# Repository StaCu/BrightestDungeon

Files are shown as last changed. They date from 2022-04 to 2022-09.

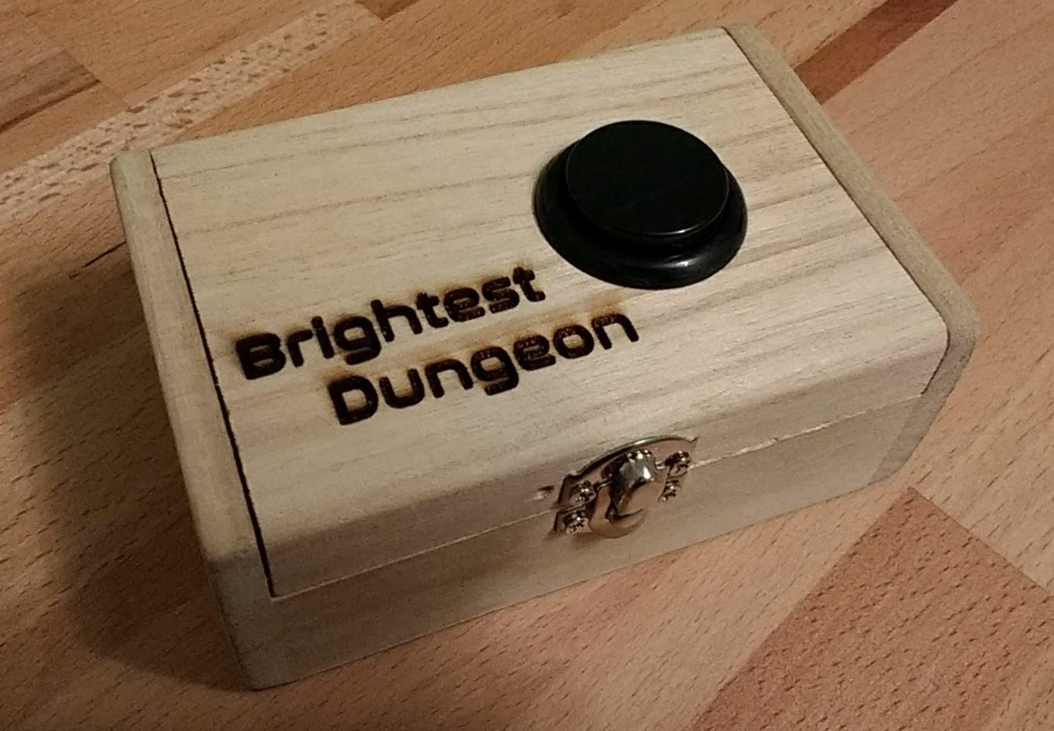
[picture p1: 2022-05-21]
cad/img/2022-04-29 Laser Engraving.jpeg

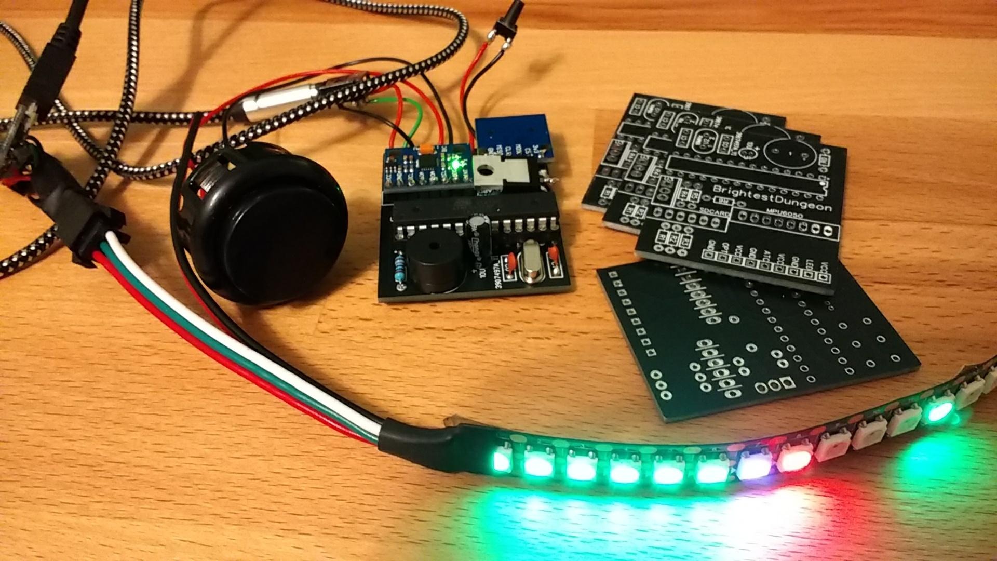
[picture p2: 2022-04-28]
cad/img/2022-03-05 PCB.jpeg

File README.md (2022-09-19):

# Brightest Dungeon

A 1D dungeon arcade&puzzle game inspired by a game I saw at 35C3.

BrightestDungeon is rather simple: You are the green dot and can move on a one dimensional led strip, but beware the red dots!
Fend for yourself against the evil monsters and progress through the different levels of the dungeon.
But keep in mind that BrightestDungeon is, at heart, a puzzle game.
Finishing a floor is not as simple as killing all the enemies within it.
You will have to prove your wits and worthiness by solving the puzzle on each floor.

## Getting it up and running

The minimal hardware requirements to play BrightestDungeon include a microcontroller (Atmega328p), LED strip (WS2812), potentiometer and a button.
An accelerometer (MPU6050), sound driver and sdcard reader can improve the experience.
The code can be easily ported to other platforms as well.
Alternatively, one can also be play from the linux terminal.

### Microcontroller

Each supported platform has a file platform/\<platform\>/Platform.md , which contains information about which components are
required, how to wire them as well as information about how to en-/disable some of them.

To program the microcontroller with Arduino IDE, open BrighestDungeon.ino and copy the required libraries.
To upload the code with PlatformIO, use one of the following lines:

```
pio run -e <environment> --target upload
pio run -e <environment> --target upload && pio device monitor
```

### Simulator

To run the simulator and play the game inside the terminal, run:

```
pio run -e simulator && .pio/build/simulator/program
```

The ncurses library is a prerequisite.
It is preinstalled on most linux distibutions, or can be installed using:

```
sudo apt install libncurses-dev
```

You can play using A (left), D (right), S (attack), E (options), Q (quit).
However, this meant to be more for debugging and creating new levels rather than actually playing BrightestDungeon.

## Project Structure

The following is a simplified structure of the project to show where to find information about its different parts.

folder/file                  | content
-----------------------------|-------------
cad/                         |
\|-- img/                    | some images to look at
\|-- Build Instructions.md   | how to build the game
dng/                         |
\|-- 0-f/                    | sdcard-loadable dungeons
\|-- Create Dungeon.md       | how to create new dungeons/floors/rooms
\|-- Entity Cheat Sheat.md   | explanation of each entity
\|-- Runtime Settings.md     | explanation of runtime settings
\|-- template.txt            | template for a dungeon room
platform/                    |
\|-- lib/                    | common libraries
\|-- \<platforms\>/          | 
\|-- \|-- lib/               | libraries for each platform
\|-- \|-- Platform.md        | information about the platform
\|-- Porting.md              | how to port to a new platform
src/                         | 
BrightestDungeon.ino         | entry point for ArduinoIDE
LICENSE                      | GPLv3
platformio.ini               | build tool instructions
README.md                    | this file
sdcard.sh                    | copy everything to an sdcard

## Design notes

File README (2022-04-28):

# Brightest Dungeon

A 1D dungeon arcade&puzzle game inspired by a game I saw at 35C3.

Brightest Dungeon is rather simple: You are the green dot and can move on a one dimensional led strip, but beware the red dots!
Fend for yourself and progress through the different levels of the dungeon.
But keep in mind that Brightest Dungeon is, at heart, a puzzle game.
Finishing a floor is not as simple as killing all the enemies within it.
You will have to prove your wits and worthiness by solving the puzzle each floor represents.

## Entity Cheat Sheet

List of all the entities, puzzle pieces and stuff to watch out for in the dungeon.

Entity             | Visual              | Description
-------------------|---------------------|-------------------------
Lives              | green/blue/red dots | the first few leds show how many lives you have left (not so important when using checkpoints)
Hero               | green/blue dot      | you
 - Goal            | green/blue          | your goal (not every room has one, always at the end)
 - Sword           | cyan line           | your default attack
 - Shot            | cyan dot            | your special attack (lost on death)
Item               |                     |     
 - sword/shot      |                     | swap attack type
 - set color green |                     | change your color to green
 - set color blue  |                     | change your color to blue
 - invert control  |                     | invert control
 - extra life      |                     | +1 live (capped at MAX_LIVES)
-------------------|---------------------|-------------------------
Monster            | red dot             | move back and forth, (do not touch!)
 - Spawner         | none                | spawns new monsters
Worm               | moving red line     | a bit smarter than normal monsters
Boss               | red line            | has multiple lives and spawns monsters
-------------------|---------------------|-------------------------
Button             | white/gray line     | [^0] with a timed behaviour
Door               | white line          | enter another room on the same floor
Fog                | pink line           | hides anything underneath it
ForceField         | blue/green flicker  | you can only pass through if you have matching colors
Lava               | orange flicker      | save to cross when it does not flicker
Mine               | yellow dot          | explodes (do not touch!)
Portal             | orange/blue line    | the cake is a lie!
Switch             | white/gray line     | [^0] with a back and forth behaviour
Wall               | white line          | blockade
Water              | moving blue dots    | the current drags you along with it

[^0] Brightest Dungeon employs a masking system to change parts of the active room.
Loading a room loads EVERY entity within it.
However, each entity has a mask that determines whether it is visible, updated and part of collisions.
Moving over a button or pressing a switch changes which entities are masked (though some are always there).

## Getting it up and running

Here is a list of the different hardware elements required to run the game.

### Atmega328P (16MHz)

The game was originally developed for the Atmega328P, using it will not require any changes to the code base and all features
can be used. The Atmega328P must be clocked at 16MHz, because the LEDs used (WS2811) use a protocol depending on the correct
timing. The code to transmit the LED data was written so it works for 16MHz.

### Atmega168P (16MHz)

The game works on the smaller version of the Atmega328P, the Atmega168P, as well. However, some settings must be
disabled/reduced, because the Atmega168P doesn't have enough sram and progmem required for those features.
In src/Settings.h set ...
//#define USE_MPU6050_CONTROLLER
#define LED_STRIP_COUNT 300
#define LED_STATUS_COUNT 0
#define POOL_SIZE 40
#define ENABLE_SOUND false
#define SHORTEN_INTERNAL_DUNGEON true
#define ENABLE_FILE_LOADER false
#define USE_EEPROM false
#define ENABLE_LOGGING false
... and the program code should turn out to fit onto the Atmega168P together with a small bootloader.

### WS2812B

To save SRAM (and PROGMEM), the LED control code has been written in Assembler and is only compatible with WS2811 LEDs (and WS2812).
While the code is capable of addressing up to 2^16 LEDs, the MCU reaches its limit at around 500 of them, beyond of which
it is not capable of delivering 50 refreshes per second. Increasing UPDATE_TIME in src/Settings.h will allow for more
LEDs.
By default, the minimum number of LEDs is 100, as the level layout suffers from too few pixels.
Both, LED_MIN_COUNT and LED_STRIP_COUNT can be changed in src/Settings.h .
Some LED strips are terrible with regards to color correctness. 
#define COLOR_PALETTE 1
switches to a second color palette that ensures the different entities are still distinguishable (but the game will look worse).

### Simple Controller

The simple controller consists of a button for attacking and a potentiometer for moving.

### MPU6050

The better controller consists of a button for attacking and the MPU6050 for moving.

### Passive Buzzer

Used to generate the sound.

### SDCard Adapter and SDCard

To allow for new dungeons without the need to recompile, BrightestDungeon is capable of loading levels from an SDCard.

### Button

One button for entering the in game options menu.

### Pins

Most of the pins have been hardcoded (but the assembler code can of course be changed).
The default values are:
Usage             | Pin
------------------|---------------
Simple Controller |
 - Potentiometer  | A5
 - Attack Button  | D2
MPU6050           |
 - SCL            | A5
 - SDA            | A4
 - Attack Button  | D2
LED               |
 - Data           | D8
Sound             |
 - Passive Buzzer | D9, D10
Random            | A1 (to make random numbers more random)
Options           | D3
SD Card           | (many sdcard modules use 3.3V)
 - MOSI           | D11
 - MISO           | D12
 - CLK            | D13
 - CS             | D4

Connecting Ground and Vcc is all that is left.

## Setup

The compile time settings are all listed and explained within src/Settings.h .

### Microcontroller

To program the microcontroller with Arduino IDE, open BrighestDungeon.ino with it.
To upload the code with PlatformIO, use one of the following lines:

```
pio run --target upload
pio run --target upload && pio device monitor
```

### Simulator

The simulator can be started with a directory from which to load external dungeons and store the eeprom simulation and logging information.
To run the simulator and play the game inside the terminal, run:

```
mkdir build
cd build/
cmake .. 
make dungeon
./dungeon ../
```

The ncurses library is a prerequisite (preinstalled on most linux distibutions).
You can play using A (left), D (right), S (attack), E (options), Q (quit).
However, this meant to be more for debugging and creating new levels rather than actually playing BrightestDungeon.

### Secret Code

To generate a secret morse code that can be integrated into the game write the text to secret/main.cpp and run:

```
mkdir build
cd build/
cmake .. 
make secret
./secret
mv Secret.h ../src/Secret.h
```

###

To copy everything to an sdcard, run:

```
./sdcard.sh <path>
```

## Creating new Dungeons, Floors and Rooms

See /dng/README on how to write and load your own dungeons.

## In Game Settings

The runtime settings are listed within src/level/Options.cpp.
While they can be changed at runtime, their default values can be set in src/Settings.h.
When using the EEPROM feature to remember the settings, however, those default values become less important.

The options menu can be opened by pressing the OPTIONS_PIN.
This will show a level with multiple white, gray and green dashes.
Placing the hero on one of them and attacking will change the settings (the green dashes are only spacers and do nothing).

Options layout (WW: white, WG: white/gray, GG: green):
x    | description
-----|---------------------------------
WW   | callibrate the controller
WG   | invert the controller direction
GG   | ---
WW   | led_count --
WW   | led_count ++
WW   | brightness --
WW   | brightness ++
WW   | volume --
WW   | volume ++
GG   | ---
WG   | enable/disable checkpoints
GG   | ---
WG   | dungeon0 [^1]
WG   | dungeon1 [^1]
WG   | dungeon2 [^1]
WG   | dungeon3 [^1]
GG   | ---
WG   | floor0 [^2]
WG   | floor1 [^2]
WG   | floor2 [^2]
WG   | floor3 [^2]
WG   | floor4 [^2]
WG   | floor5 [^2]
WG   | floor6 [^2]
WG   | floor7 [^2]
GG   | ---
WW   | reload options from eeprom
WW   | write changes to eeprom
GG   | ---
Goal | exit options (keep changes until the next restart)

[^1] select one of 16 dungeons (0: internal, 1-15: sdcard);
     when opening the options, this will show the currently selected dungeon
[^2] select a floor from this dungeon and start from there (skip the previous floors);
     when checkpoints are disabled, this floor serves as a start point after loosing all lives;
     when opening the options, this will show the currently selected floor

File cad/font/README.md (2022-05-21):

# Font

I used Nasalization (https://typodermicfonts.com/).

Laser Engraving:
54mm * 20mm

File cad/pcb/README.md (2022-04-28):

# Parts

U1:         10uF Capacitor
C0,C1:      22pF Ceramic Capacitor
U2:         16MHz Quarz Crystal
R0:         10k Ohm Resistor
R1,R2,R3:   2k Ohm Resistor
R4,R5,R6:   1k Ohm Resistor
U3:         LM1117T 3.3V Voltage Regulator

Atmega328p
SDCard Reader

MPU6050 or Potentiometer
Button (ATC + GND)
Button (OPT + GND)
WS2811 (LED)

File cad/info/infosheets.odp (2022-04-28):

## Brightest Dungeon

A 1D Dungeon aRcade & Puzzle Game

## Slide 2

Brightest Dungeon is rather simple: You are the green dot and can move on a one dimensional led strip, but beware the red dots! Fend for yourself and progress through the different levels of the dungeon.

But keep in mind that Brightest Dungeon is, at heart, a puzzle game. Finishing a floor is not as simple as killing all the enemies within it. You will have to prove your wits and worthiness by solving the puzzle each floor represents.

## Hero

You

Your goal

Move by tilting the Gamebox

## Monster

Moves back and forth (do not touch!)

## Attack

Attack by pressing the button

Sword: your default attack

Shot: your special attack (lost on death)

## Lives

Lives

+1 live

Loosing all lives

resets the current

floor

2 dots orbiting another dot

## Colors

Forcefield

(flickers green/blue)

You can only pass through if you have matching colors

Colorchange

(green/blue)

Change your color to green/blue

## Worm

A bit smarter than normal monsters

## Boss

Has multiple lives and spawns monsters

If a boss is present, you can only progress

to the next floor after defeating it

## Button

Move over to make changes to the floor

(may revert after some time)

Colors darken on activation

## Door

Enter another room on the same floor

## Fog

Hides anything underneath it

## Lava

Save to cross when it does not flicker

Flickers

## Mine

Explodes (do not touch!)

## Portal

The cake is a lie!

Go in here...

...come out here!

## Switch

Press to make changes to the floor

(press again to revert)

Colors invert on activation

## Wall

Blockade, can’t pass through

## Water

The current drags you along with it

Pattern moves

## OPTIONS 1

Calibrate

Invert Controls

++++++

#LED --

#LED ++

Brightness --

Brightness ++

Volume --

Volume ++

++++++

Leaving the Level keeps the changes until the next restart

Writing to EEPROM saves the changes permanently

## OPTIONS 2

Enable/Disable Checkpoints

++++++

Select Dungeon [0-15] (0: Internal, 1-15: SDCard)

++++++

Select Start Floor [0-255]

++++++

Read Options from EEPROM

Write Options to EEPROM

++++++

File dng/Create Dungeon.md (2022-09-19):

# Creating new Dungeons, Floors and Rooms

First up, in Platform.h ENABLE_FILE_LOADER must be defined as true.

## Background

Brightest Dungeon loads a room by using the following path scheme:
/dng/X/YYY/ZZZ.txt
X: dungeon number [0-f]
YYY: floor number [0-255]
ZZZ: room number [0-255]

If the file does not exist, it will be treated like the player having beaten the entire dungeon (i.e. showing the victory animation).
If the file does exist, loading it will be successful, no matter the content.
Anything that does not match the correct syntax will be ignored or interpreted as 0.

## Creating a dungeon

A dungeon simply consists of multiple floors, starting with floor 000.
After finishing a floor, the next one is loaded.
If no room 000 exists within the next floor, the player has finished the dungeon.

## Creating a floor

A floor consists of one or more rooms, with one room being the 000 (the first room of the floor).
Doors can be used to switch between the different rooms.
Due to limited memory, (re-)loading a room will restore every entity that got destroyed previously (this actually makes for an interesting puzzle mechanic).

## Creating a room

A room is 250 units long and updated 50 times per second (every UPDATE_TIME ms).
Each unit consists of 32 sub steps.
 => speed of 10 results in 10 * 50 / 32 = 15.625 steps/second
I find that a speed of 3 to 20 is reasonable for monsters and water current.

The text file describing a room is read line by line.

### Entities

Each line contains one entity and its parameters.

 name       | parameters               | length | hint
------------|--------------------------|--------|-----
 NEXT       |                          |        | there is a goal at the end to progress to the next floor [^0]
 END        |                          |        | there is no goal at the end to progress to the next floor (optional) [^0]
 RESET      | mask                     |        | resets the specified bits of the global mask
------------|--------------------------|--------|-----
 HERO       | mask pos                 |    1   | must be a part of the level (otherwise it's a boring level...)
 \|         |                          |        | ofter death the previous spawn position is used (usually that is what you want)
 ITEM       | mask pos type            |    1   |
------------|--------------------------|--------|-----
 MONSTER    | mask pos speed           |    1   |
 BOSS       | mask pos pos pos         |   16   | a boss respawns 2 times
 WORM       | mask pos speed           |   16   |
 SPAWNER    | mask time time pos speed |    0   | the 1st time is the first activation,
 \|         |                          |        | the 2nd the interval for every
 \|         |                          |        | recurring activation
------------|--------------------------|--------|-----
 BUTTON     | mask pos op time time    |    6   |
 DOOR       | mask pos room pos        |    6   | the 2nd position is the destination
 FOG        | mask pos size speed      | size   |
 FORCEFIELD | mask pos color           |    6   |
 LAVA       | mask pos size time time  | size   | the 1st time is the first activation,
 \|         |                          |        | the 2nd the interval for every
 \|         |                          |        | recurring activation
 MINE       | mask pos                 |    1   |
 PORTAL     | mask pos pos             |    6   | the second position is the second portal
 SWITCH     | mask pos op              |    6   |
 WALL       | mask pos size            | size   |
 WATER      | mask pos size speed      | size   |
------------|--------------------------|--------|-----

[^0] anything after this will be ignored

### Parameters

 name  | range        | description
-------|--------------|-------------
 pos   | [0, 250]     |
 size  | [0, 250]     |
 speed | [-128, 127]  | note: the max player speed is slightly below 100
 time  | [0, 255]     | multiply by 100ms, 0 means no repetition
 room  | [0, 255]     | 
 type  | [1, 7]       | 0: set color to green (0), (default)
 \|    |              | 1: set color to blue (1),
 \|    |              | 2: swap sword <=> shot, (default: sword)
 \|    |              | 3: invert control direction, (default: not inverted)
 \|    |              | 4: extra life,
 color | [0, 1]       | 0: color green (0)
 \|    |              | 1: color blue (1)
 op    | [0, 255]     |
 mask  | [0, 255]     |
-------|--------------|-------------

Note: use binary notation by prefixing the number with a b or 0b (128 or 0b10000000).

### MASKING

Masks are a big part of the puzzle game. 
Each entity has a mask and there is a global mask.
The mask is used to decide, whether an entity is active.
Only then is it drawn, updated, and considered for collisions.
```
active = (entity_mask & global_mask) == entity_mask;
```

Switches and Buttons can change the global mask with the op parameter.
```
new_global_mask = global_mask ^ op;
```

When loading a new floor, the global mask is reset to 0b11110000 (this also means that it persists accross rooms and deaths on the same floor).
An entity with mask 0b10000000 will be active until the msb is flipped.
An entity with mask 0b00000001 will be inactive until the lsb is flipped.
An entity with mask 0b00000000 will always be active.

### COMMENTS

There are no comments.
If the first word does not match any of the keywords listed above, the line will be ignored.
Anything behind a complete command is also ignored.
A line has a maximum of FILEIO_BUFFER_SIZE (64) characters, anything beyond that is ignored.
If a number is missing or contains other symbols, it is interpreted as a 0.
 => there are no errors apart from "file not found".

```
BLABLA      this line will be treated as a "comment", because BLABLA is not a keyword
HERO as     this line will do the same as HERO 0 0, as does the next one
HERO                                                               1 2  (more than 64 chars)
HERO(0,0)   '(' ',' and '\t' are treated the same as ' '
```

The maximum amount of entities in the same room is POOL_SIZE, two of which are reserved for attacks.
Loading more entities will not do anything.
Keep in mind that a PORTAL comprises two entities.

### EXAMPLE

```
++ MAX LINE LENGTH +++++++++++++++++++++++++++++++++++++++++++++
HERO(0, 0)                # spawns a hero at position 0
LAVA(0, 50, 25, 0, 20)    # creates a lava pool at position 50
                          # with length 25. it activates after
                          # 0 seconds and switches between
                          # active/inactive every 20*100ms = 2sec
MONSTER(0, 200, 0)        # this monster will always show up
MONSTER(1, 210, 10)       # this monster is masked
NEXT                      # end of level
                          # once the hero reaches the goal, the
                          # next floor will be loaded
++ MAX LINE LENGTH +++++++++++++++++++++++++++++++++++++++++++++
```

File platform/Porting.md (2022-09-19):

# Porting Brightest Dungeon

- Put required libraries in platform/\<platform\>/lib
- Put platform specific code in platform/\<platform\>/lib/Platform/src
- Put information about the platform in platform/\<platform\>/Platform.md (minimum: pin usage and required libraries)
- Add new environment to platformio.ini

## Platform Specific Code

The platform specific code must implement all functions from platform/Platform.h
The files library.json and library.properties are also required for the build tool to find the code.
Folder structure:

folder/file                              | content
-----------------------------------------|-------------
platform/                                |
\|-- lib/                                | common libraries
\|-- \<platform\>/                       |
\|-- \|-- lib/                           | platform specific libraries
\|-- \|-- \|-- lib1/                     | required libraries
\|-- \|-- \|-- Platform/                 | 
\|-- \|-- \|-- \|-- src/                 | platform specific code
\|-- \|-- \|-- \|-- \|-- Platform.h      |
\|-- \|-- \|-- \|-- \|-- Platform.cpp    |
\|-- \|-- \|-- \|-- \|-- file1           |
\|-- \|-- \|-- \|-- library.json         | required by PlatformIO
\|-- \|-- \|-- \|-- library.properties   | required by ArduinoIDE
\|-- \|-- pcb/                           | PCB files
\|-- \|-- Platform.md                    | information about the platform
\|-- Platform.h                          | template for platform specific code
\|-- Porting.md                          | how to port to a new platform
platformio.ini                           | build tool instructions

See platform/simulator/ or platform/atmega328p for a simple example.

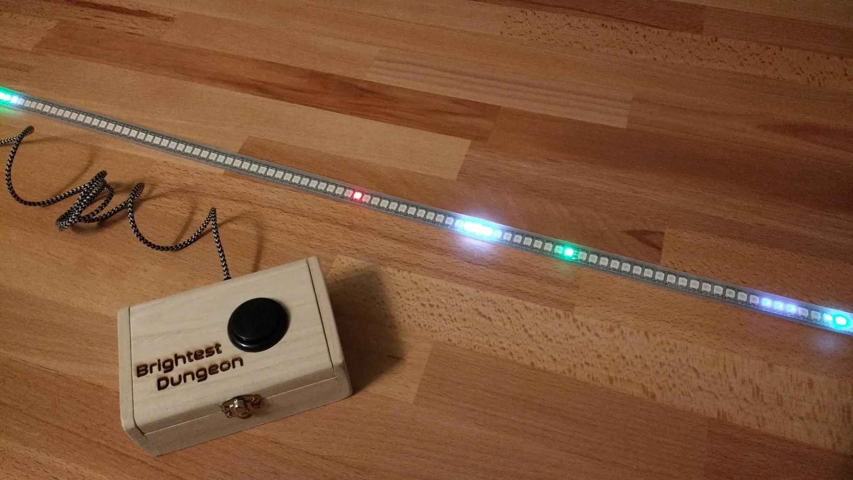
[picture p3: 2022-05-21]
cad/img/2022-05-21 2nd.jpeg

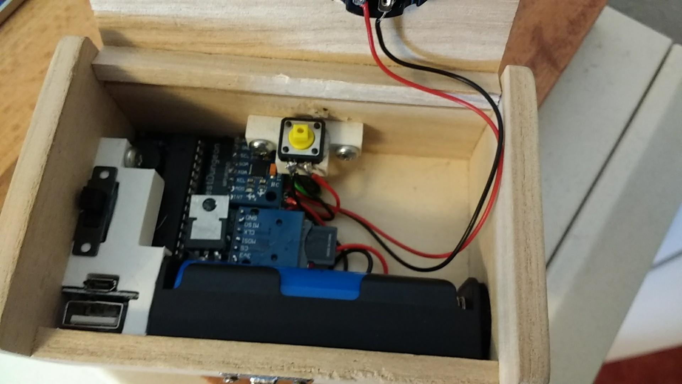
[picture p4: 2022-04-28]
cad/img/2022-04-16 Battery.jpeg

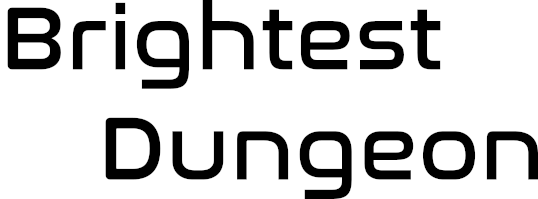
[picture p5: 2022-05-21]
cad/font/Text.png

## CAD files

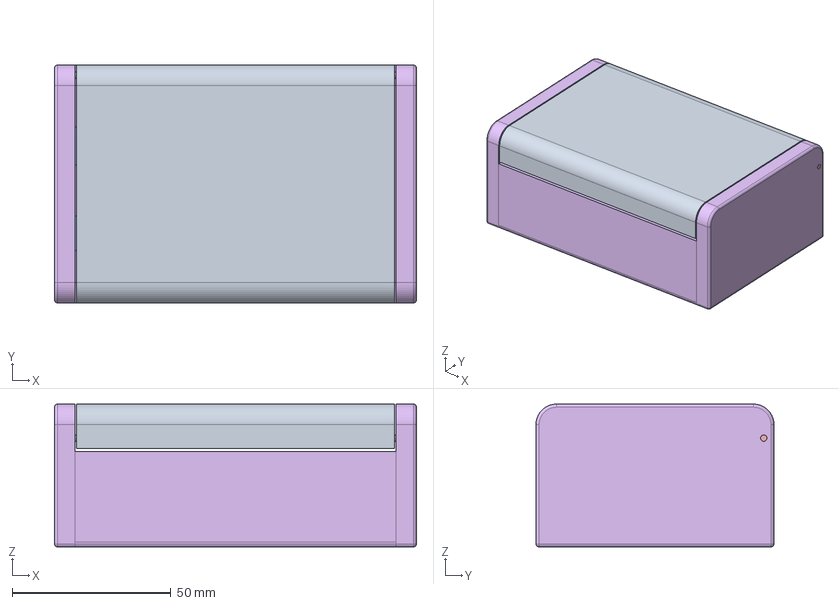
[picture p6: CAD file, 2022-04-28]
cad/box/Box.FCStd
114.0 x 75.0 x 45.0 mm
Top
ConnectorHolder
BMSHolder
BoxPinLeft
BoxPinRight

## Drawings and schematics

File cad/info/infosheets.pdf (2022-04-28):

# Brightest Dungeon

### A 1D Dungeon aRcade & Puzzle Game

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

# Hero

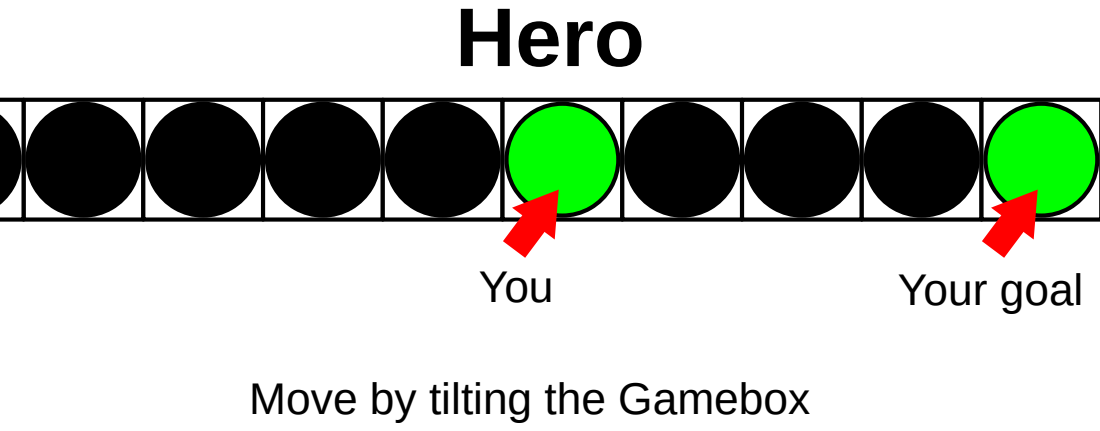
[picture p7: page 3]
You; Your goal

Move by tilting the Gamebox

# Monster

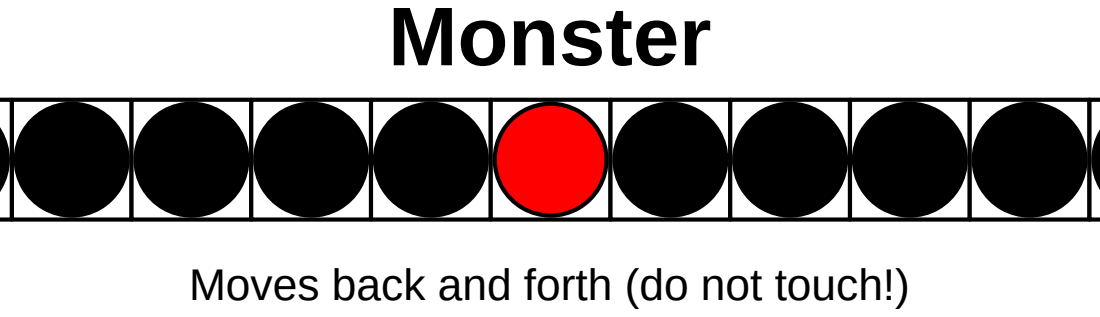
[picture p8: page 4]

Moves back and forth (do not touch!)

# Attack

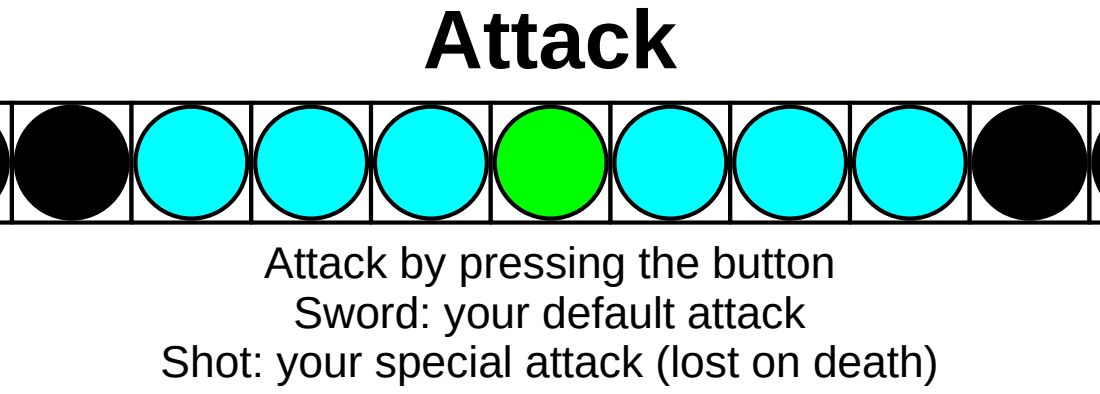
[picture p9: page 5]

Attack by pressing the button
Sword: your default attack
Shot: your special attack (lost on death)

# Lives

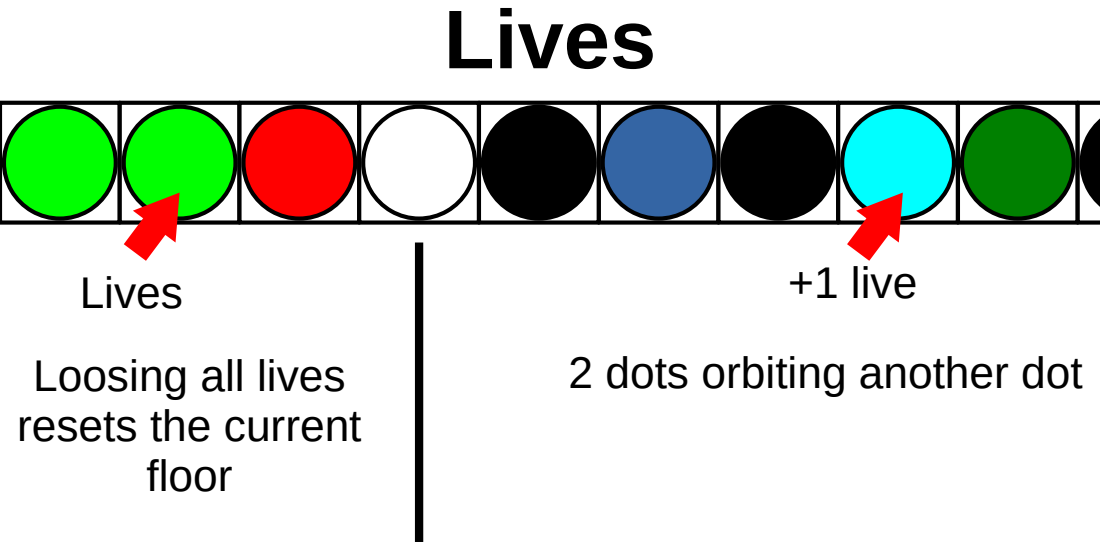
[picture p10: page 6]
Lives; +1 live; Loosing all lives; 2 dots orbiting another dot

resets the current
floor

# Colors

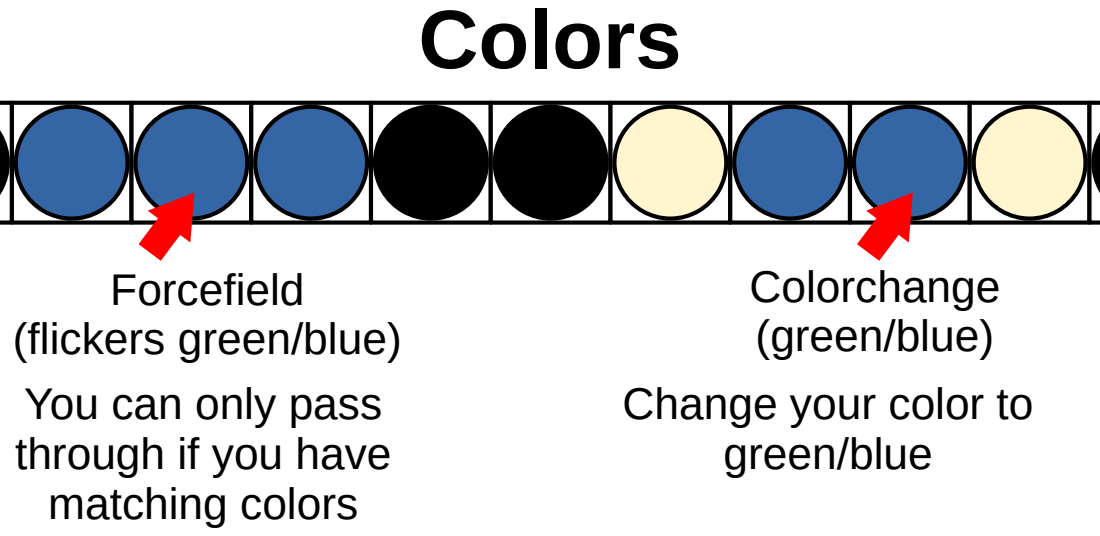
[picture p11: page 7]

Forcefield
(flickers green/blue)
You can only pass
through if you have
matching colors

Colorchange
(green/blue)
Change your color to
green/blue

# Worm

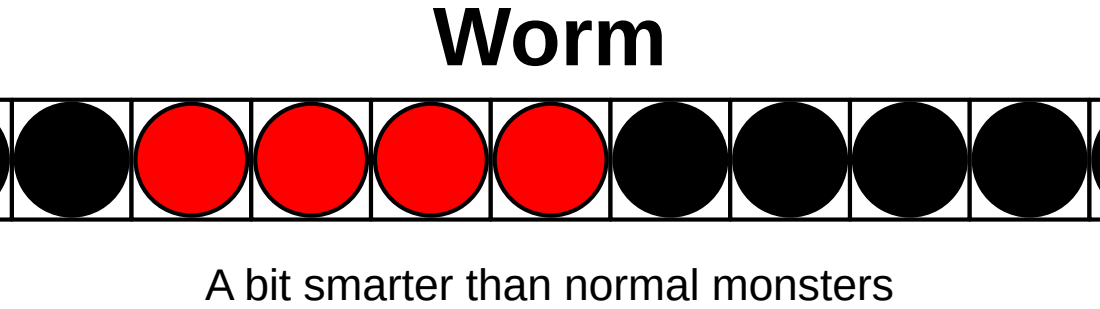
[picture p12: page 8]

A bit smarter than normal monsters

# Boss

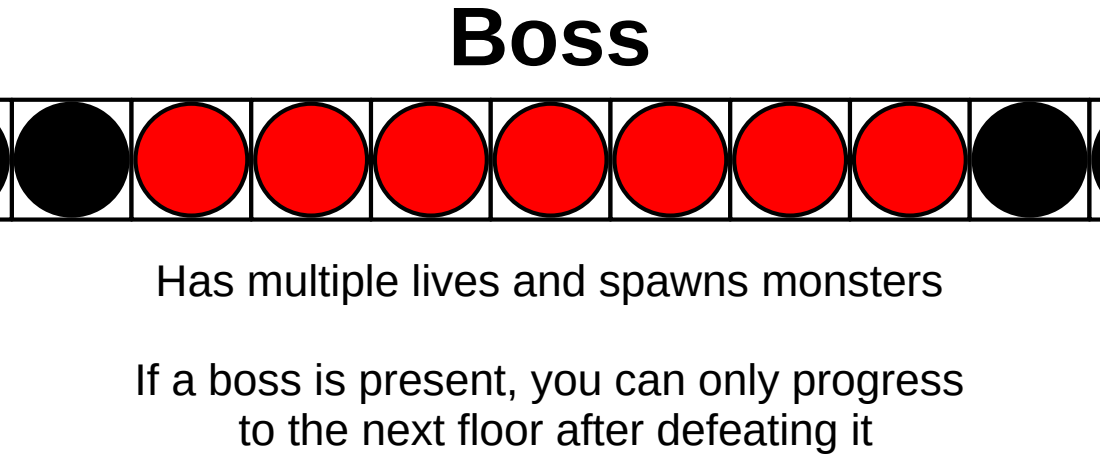
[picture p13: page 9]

Has multiple lives and spawns monsters

If a boss is present, you can only progress
to the next floor after defeating it

# Button

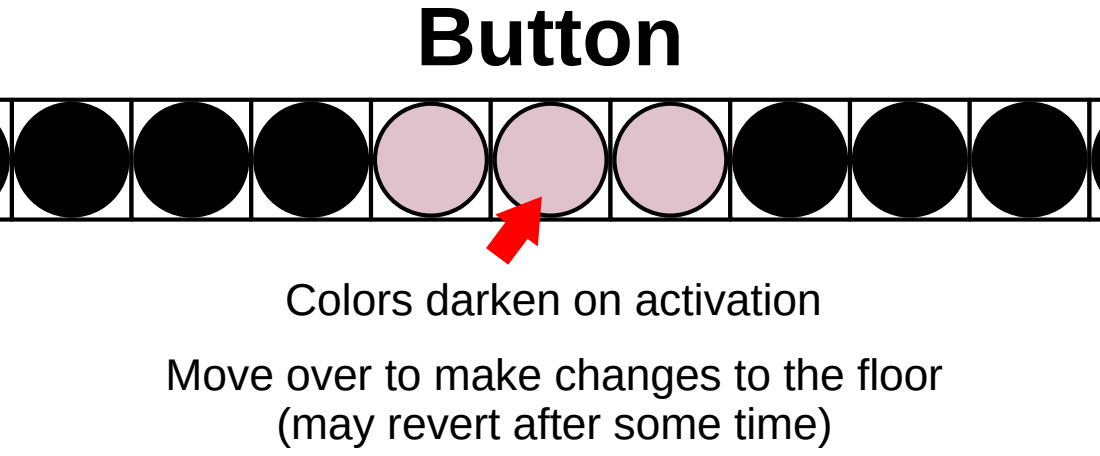
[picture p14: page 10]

Colors darken on activation
Move over to make changes to the floor
(may revert after some time)

# Door

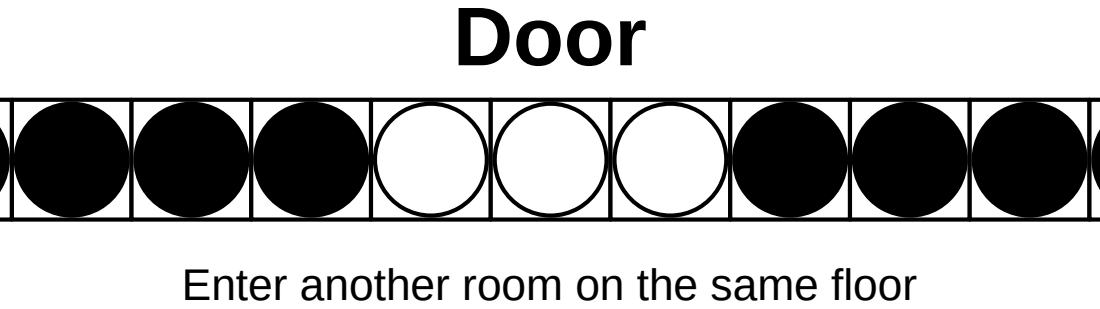
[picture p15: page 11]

Enter another room on the same floor

# Fog

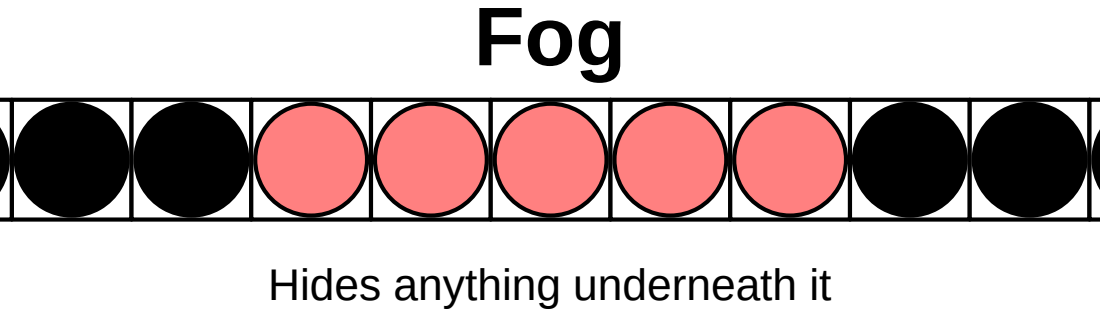
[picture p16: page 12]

Hides anything underneath it

# Lava

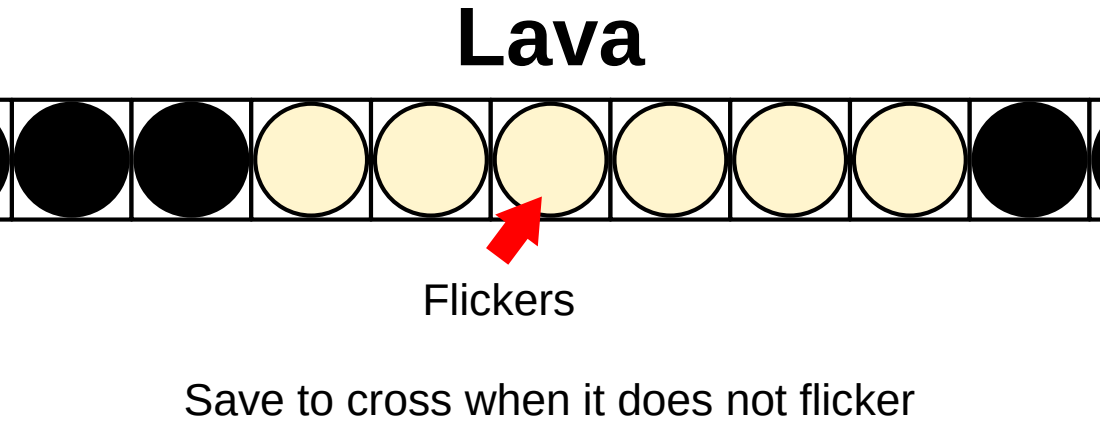
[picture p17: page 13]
Flickers

Save to cross when it does not flicker

# Mine

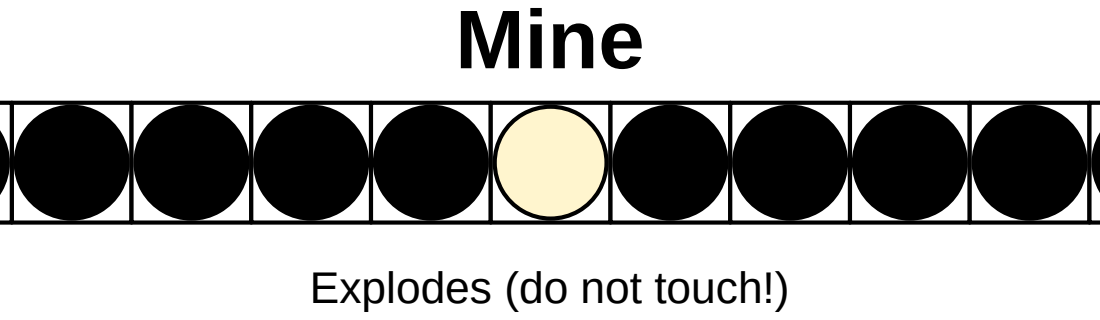
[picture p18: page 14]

Explodes (do not touch!)

# Portal

Go in here...; ...come out here!

The cake is a lie!

# Switch


Colors invert on activation
Press to make changes to the floor
(press again to revert)

# Wall


Blockade, can’t pass through

# Water

Pattern moves

The current drags you along with it

# OPTIONS 1

Calibrate
Invert Controls
++++++
#LED --

#LED ++

Brightness --
Brightness ++
Volume --
Volume ++
++++++

Leaving the Level
keeps the changes until
the next restart

Writing to EEPROM
saves the changes
permanently

# OPTIONS 2

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

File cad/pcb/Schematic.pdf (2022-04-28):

## MPU6050

## Pads



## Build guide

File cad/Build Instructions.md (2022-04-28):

# Parts

### Box

See box/*

Schatullenverschluss

3.5mm audio sockets & cable

### PCB

See pcb/*

### Battery

134N3P 5V USB LiPo Charger

18650 LiPo Battery
18650 LiPo Battery Holder

Switch

some felt so it fits in tight but is still removable

### LED

WS2812B Strip (e.g. 1m 144 LEDs)

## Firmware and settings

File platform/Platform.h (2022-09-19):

#pragma once

// # ================================================================ #
// # ::  INCLUDE                                                   :: #
// # ================================================================ #

#include <stdint.h>

// # ================================================================ #
// # ::  MISC                                                      :: #
// # ================================================================ #

#define MAX_LIVES              5
#define MAX_ENTITY_COUNT       42

// # ================================================================ #
// # ::  PLATFORM                                                  :: #
// # ================================================================ #

#ifndef F
#define F(x) x
#endif

#ifndef PROGMEM
#define PROGMEM
#endif

#define ENTRY_POINT(x) \
int main() { \
    platform_init(argc, argv); \
    {x;} \
    return 0; \
}

void platform_init(int argc, const char **argv);

void platform_deinit();

void platform_update();

void platform_poll();

uint8_t platform_read_byte_progmem(const uint8_t *ptr);

char platform_read_byte_progmem(const char *ptr);

// # ================================================================ #
// # ::  TIMING                                                    :: #
// # ================================================================ #

#define STARTUP_SAFETY_TIME    1000

#define UPDATE_TIME            20
#define STAND_BY_TIMEOUT       64000
#define STAND_BY_TIMEOUT_RESET 74000

#define ENABLE_WATCHDOG       false

uint32_t platform_millis();

void platform_watchdog_enable();

void platform_watchdog_disable();

void platform_watchdog_reset();

// # ================================================================ #
// # ::  LED STRIP                                                 :: #
// # ================================================================ #

#define LED_STRIP_COUNT 300
#define LED_STATUS_COUNT 0

#define LED_MIN_COUNT 100
#define LED_MAX_COUNT (LED_STRIP_COUNT + LED_STATUS_COUNT)

#define LED_MAX_BRIGHTNESS 5

#define LED_COLOR_CORRECT_R 255
#define LED_COLOR_CORRECT_G 255
#define LED_COLOR_CORRECT_B 255

//#define USE_HIGHER_CONTRAST_COLOR_PALETTE

#define COLOR_SWIZZLE(R,G,B) R,G,B

// the 2 most useful values for COLOR_PALETTE_INDEX_BITS are 5 and 8
// 8: each index is 8bit wide, making it really easy to iterate the indices-array in leds_show(...).
// 5: each index is 5bit wide, which is the minimum necessary to cover all colors in the game.
//    This saves some memory, however, reading from the array becomes more difficult as indices may
//    not start on a byte boundary or even cover two bytes.
// => choose 8 unless the platform is memory constrained.
#define COLOR_PALETTE_INDEX_BITS 5

void leds_init();

void leds_reset();

void leds_show(uint8_t *indices, uint8_t *palette, uint8_t index_bits, uint16_t led_count);

// # ================================================================ #
// # ::  CONTROLLER                                                :: #
// # ================================================================ #

void controller_init();

void controller_callibrate();

int8_t controller_poll_angle();

bool controller_poll_attack();

bool controller_poll_options();

bool controller_poll_turn_off();

// # ================================================================ #
// # ::  SOUND                                                     :: #
// # ================================================================ #

#define ENABLE_SOUND true
#define SOUND_MAX_VOLUME 4

void sound_init();

/**
 * configure the PWM hardware to generate a continous output with a given
 * frequency and volume
 * 
 * if (frequency == 0 || volume == 0)
 *      this will turn the PWM off
 * 
 * @param frequency 
 *      the frequency
 * @param volume 
 *      the volume [0..4]
 */
void sound_play(uint16_t frequency, uint8_t volume);

// # ================================================================ #
// # ::  LOG                                                       :: #
// # ================================================================ #

#define ENABLE_LOGGING false
#define BAUDRATE 115200
#define LOG_CONTROLLER false
#define LOG_TIMING_SLACK false

void platform_log_init();

void platform_log(const char *text);

void platform_log(int64_t val);

void platform_logln(const char *text);

void platform_logln(int64_t val);

#if ENABLE_LOGGING
#define LOG(x) platform_log(x)
#define LOG_LN(x) platform_logln(x)
#else
#define LOG(x)
#define LOG_LN(x)
#endif

// # ================================================================ #
// # ::  RUNTIME SETTINGS                                          :: #
// # ================================================================ #

#define ENABLE_RUNTIME_SETTINGS true

#define DEFAULT_TESTVALUE      1
#define DEFAULT_DUNGEON        0
#define DEFAULT_FIRST_FLOOR    0
#define DEFAULT_CHECKPOINTS    1

#define DEFAULT_LED_COUNT      144
#define DEFAULT_BRIGHTNESS     1
#define DEFAULT_VOLUME         1

#define DEFAULT_DIRECTION      1

void settings_init();

void settings_default();

void settings_check();

void settings_write(void *data, uint16_t size);

void settings_read(void *data, uint16_t size);

void settings_write_platform_specific(uint16_t offset);

void settings_read_platform_specific(uint16_t offset);

// # ================================================================ #
// # ::  FILE SYSTEM                                               :: #
// # ================================================================ #

#define ENABLE_FILE_LOADER true

#define ENABLE_INTERNAL_DUNGEON true

bool file_system_init();

void file_system_deinit();

bool file_open(const char *path);

void file_close();

bool file_has_next_char();

char file_get_next_char();

// # ================================================================ #
// # ::                                                            :: #
// # ================================================================ #

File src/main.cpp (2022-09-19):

#ifdef PLATFORM_ENTRY_POINT
/*
 * The PLATFORM_ENTRY_POINT is used by PlatformIO.
 * Arduino IDE uses the .ino file in the ../ directory.
 * However, Arduino IDE can't handle a second main function in the src/
 * directory.
 * This macro allows building with all both tool flows.
 */

#include <Platform.h>
#include "Dungeon.h"

ENTRY_POINT(
    Dungeon::setup();
    Dungeon::run();
)

#endif

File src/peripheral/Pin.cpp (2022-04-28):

#include "Pin.h"

#define PS2   (1<<ADPS0)                             //8000kHz ADC clock freq
#define PS4   (1<<ADPS1)                             //4000kHz
#define PS8   ((1<<ADPS0) | (1<<ADPS1))              //2000kHz
#define PS16  (1<<ADPS2)                             //1000kHz
#define PS32  ((1<<ADPS2) | (1<<ADPS0))              //500kHz
#define PS64  ((1<<ADPS2) | (1<<ADPS1))              //250kHz
#define PS128 ((1<<ADPS2) | (1<<ADPS1) | (1<<ADPS0)) //125kHz
#define ANALOG_V_REF     DEFAULT //INTERNAL, EXTERNAL, or DEFAULT
#define ADC_PRESCALE     PS128   //PS16, PS32, PS64 or P128(default)

uint16_t Pin::readAnalog(uint8_t pin) {
  uint16_t analog = 0;
  #ifdef SIMULATOR
    if (Simulator::getButton() == 'd') {
      analog = 0;
    } else if (Simulator::getButton() == 'a') {
      analog = 1023;
    } else {
      analog = 511;
    }
  #else
  asm volatile (
  "andi %1, 0x07    \n" //force pin==0 thru 7
  "ori  %1, (%6<<6) \n" //(pin | ADC Vref)
  "sts  %2, %1      \n" //set ADMUX

  "lds  r18, %3             \n" //get ADCSRA
  "andi r18, 0xf8           \n" //clear prescale bits
  "ori  r18, ((1<<%5) | %7) \n" //(new prescale | ADSC)
  "sts  %3, r18             \n" //set ADCSRA

  "_loop:       \n" //loop until ADSC cleared
  "lds  r18, %3 \n"
  "sbrc r18, %5 \n"
  "rjmp _loop   \n"

  "lds  %A0, %4   \n" //result = ADCL
  "lds  %B0, %4+1 \n" //ADCH

  : "=r" (analog) : "r" (pin), "M" (_SFR_MEM_ADDR(ADMUX)),
  "M" (_SFR_MEM_ADDR(ADCSRA)), "M" (_SFR_MEM_ADDR(ADCL)),
  "I" (ADSC), "I" (ANALOG_V_REF), "M" (ADC_PRESCALE)
  : "r18"
  );
  #endif
  return analog;
}

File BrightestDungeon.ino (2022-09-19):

/**
 * In order to build BrightestDungeon with ArduinoIDE,
 * copy the libraries from platform/<platform>/lib/ and
 * the required common libs from platform/lib/ to the
 * ArduinoIDE library folder.
 * The concrete list of required libs can be found in
 * platform/<platform>/Platform.md
 * Afterwards compile and upload should work normally.
 */

#include "src/Dungeon.h"

void setup() {
    Dungeon::setup();
    Dungeon::run();
}

void loop() {
    
}

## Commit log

2022-09-19 ArduinoIDE fix
2022-09-19 fixed log & watchdog
    [Platform.h, main.cpp]
2023-01-22 higher contrast between the two switch colors
